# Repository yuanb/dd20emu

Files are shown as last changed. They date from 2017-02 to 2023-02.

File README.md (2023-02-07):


# dd20emu
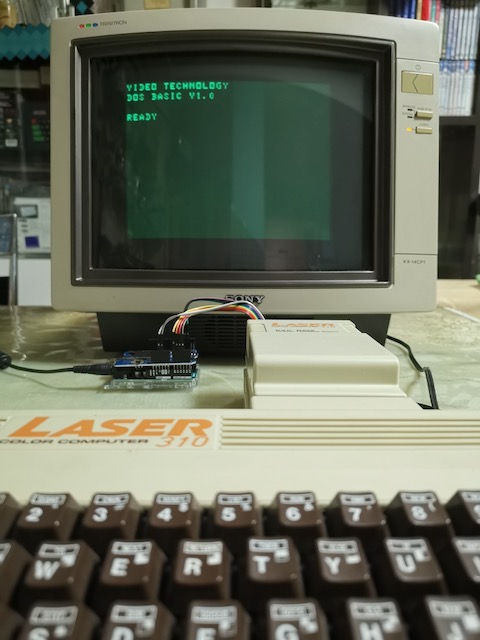
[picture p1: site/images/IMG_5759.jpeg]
dd20emu


This project is to create an Arduino UNO based Laser-200/310 DD20/DI40 Floppy drive interface and drive emulator.
At the moment this project is created, I only have a Laser-200 on hand, which has relative less amount of RAM (6K) on board. The design will include 16K (6264 SRAM x 2) memory expansion as well.

Devices I have:
* Laser 200, Basic version 1.1, 6KB RAM.
* Laser 310, Basic 2.0, 16K RAM.
* 16K RAM extension cartridge for Laser 200.
* 64K RAM extension cartridge for Laser 310.
* DD20 Floppy Drive

Todo list:
* Collect documents regarding DD20 interface and Disk image format.
* Design a 16K SRAM extension card to Laser 200
* I have about 2.25 hours length of Laser 310 data tape. They are Demo, Utilities, Games, Basic program I wrote etc. I would like to convert them to vz files. Giving they are 30 years old, the recorder I used back then was not a standard data recorder, there is only a little hope. [This link](http://www.pagetable.com/?p=32) describes how data tape encoding works on Apple I.

## Updates
2023-02-05
* Added serial terminal (Thanks https://github.com/dhansel/ArduinoFDC)
* Replaced LUT sector sync algorithm with a better one.
* Write protection

2022-02-14
Known issues:
* The emualtor is not stable when connected with DD20 floppy drive on the second port.
* Write is not supported yet.

2021-02/21  
Ported to Arduino Uno, latest code merged to develop branch.  
Used packed nibbles to store sec_lut value. 40x8 = 320 bytes.  
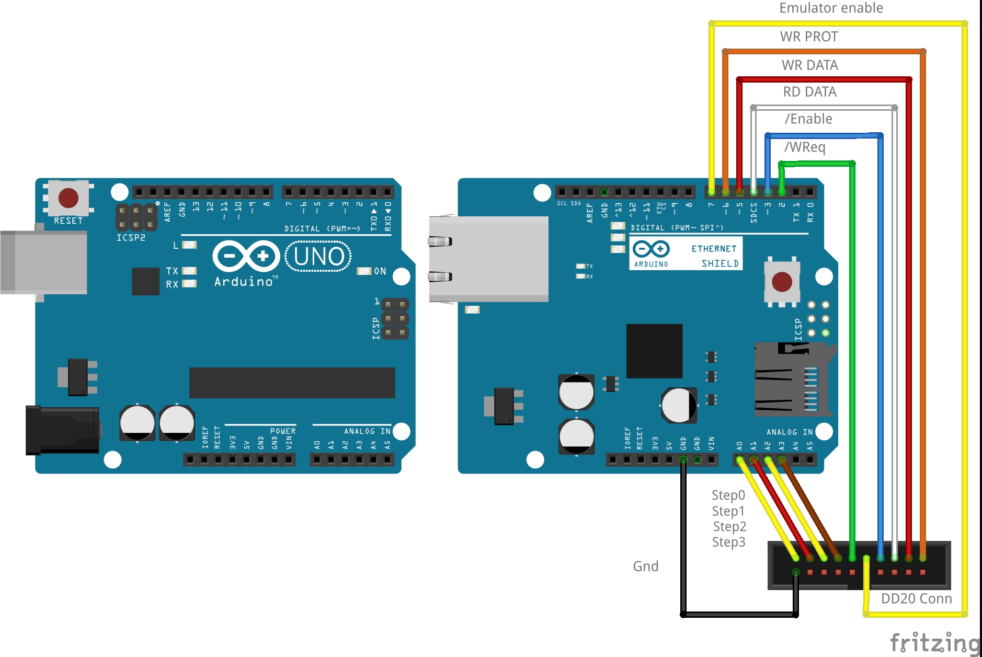
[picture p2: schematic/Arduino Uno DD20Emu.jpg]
Arduino Uno DD20 Schematic
  

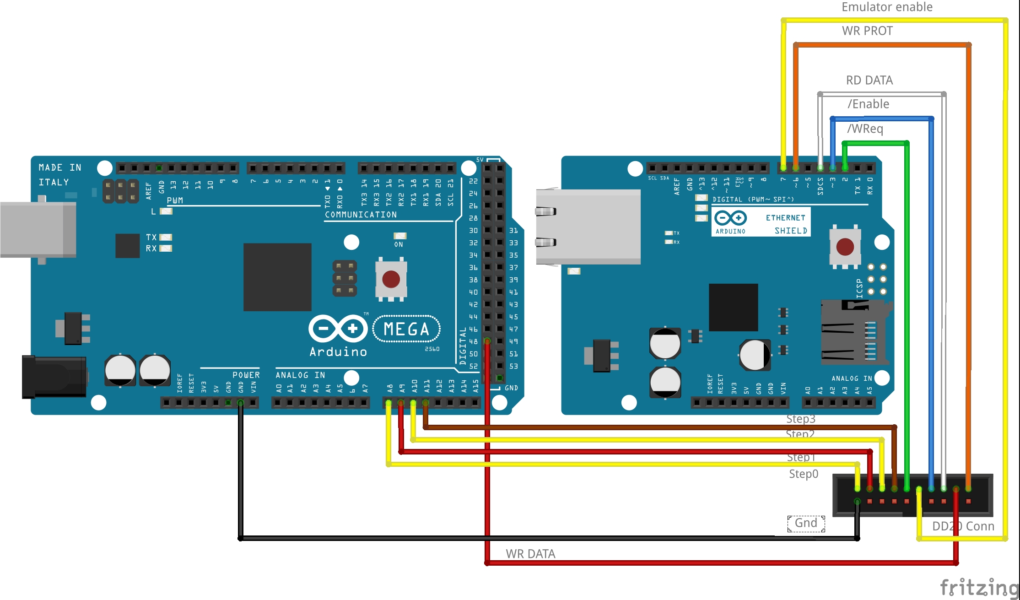
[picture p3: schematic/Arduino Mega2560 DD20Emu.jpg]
Arduino Mega2560 Schematic


2021-02/15  
Default branch: develop  
Active feature branches:  
Feature/mega2560_using_int8_sector_lut  
Feature/arduino_uno_port  

2020-11/01  
Sector lut finished. Tested with hello.dsk disk image.  

2020-10-06  
First file loadded from Arduino DD20 emu.  

2020-09-27  
First time track#0 is emulated.  
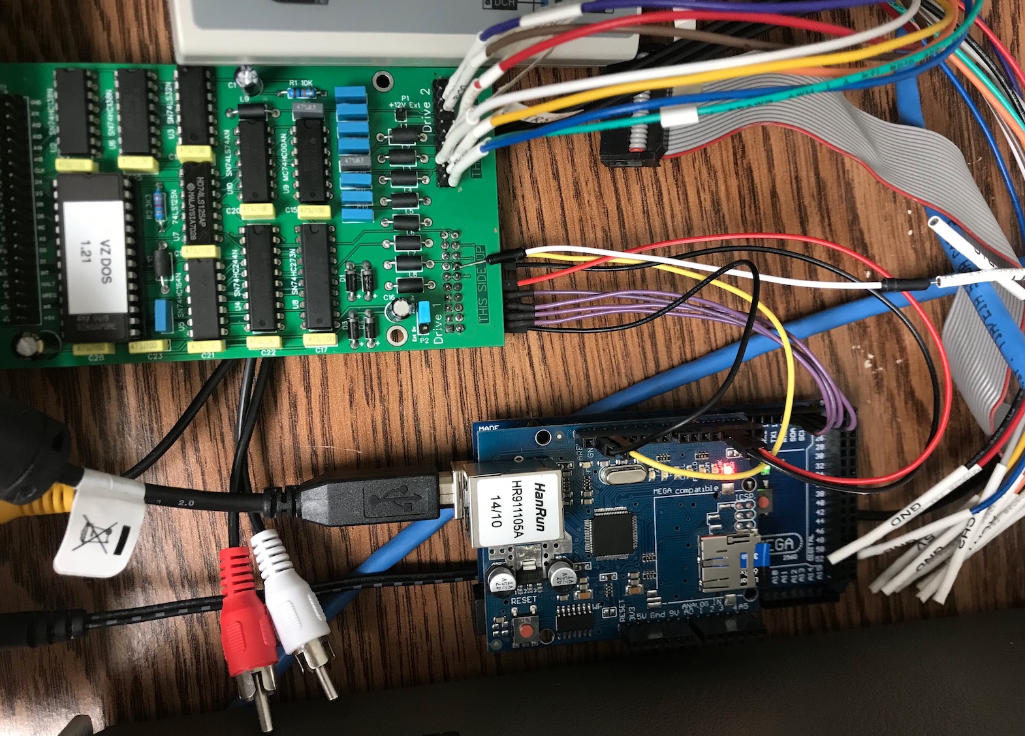
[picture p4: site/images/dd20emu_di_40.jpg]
DD20emu


2020-09-20  
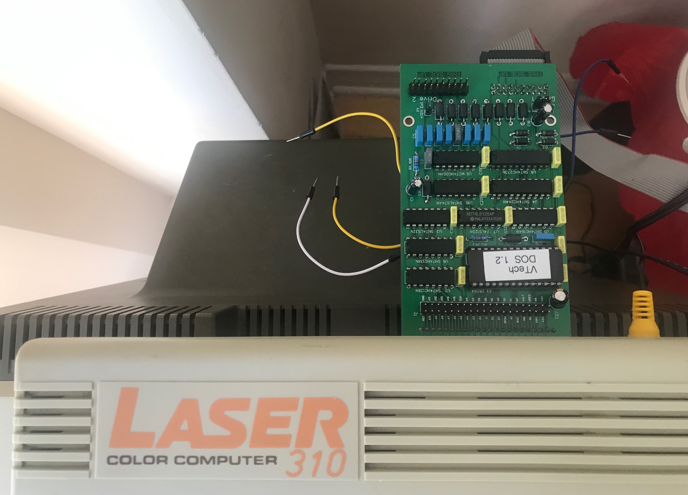
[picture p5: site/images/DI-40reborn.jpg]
DI-40 Reborn


2020-07-19  
This picture shows the RDData input is sent to 74LS164 A pin, and the D0 on port 11 read(FM Decoding). To get a byte, DI-40 needs to read from port 11 eight times.
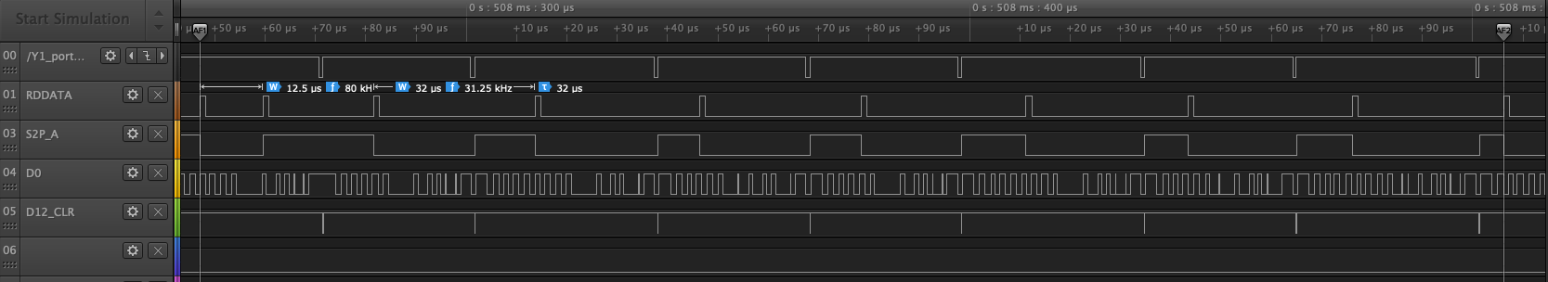
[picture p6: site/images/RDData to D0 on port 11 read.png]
FM Decoding


This picture shows the how Y1(Port11) reads generates D CLR(Port 12) pulse, 74LS164 CLK pulse and Port 12 polling.
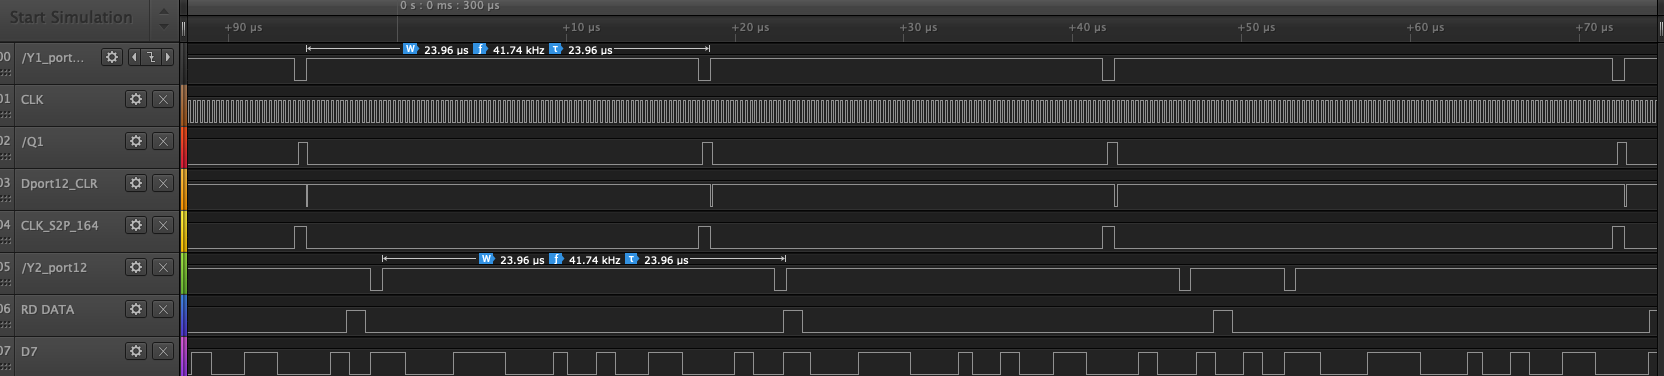
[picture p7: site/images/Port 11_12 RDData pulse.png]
D Flip-flop on port 12;74ls164 CLK and polling


2019-02-10

Started working on VZ disk reading on raspberry pi zero w.  

2019-02-02  

Finally, I got some time I can get back to this project. My plan is to use the Laser31_FPGA GPIO to connect to one or two 74AC138 decoder to trigger Arduino UNO interrupt. Arduino UNO should have enough horse power to emulate DD20 floppy drive.  
These two screen shots are the IORQ /WR and /RD requests from [Laser310_FPGA](https://github.com/zzemu-cn/LASER310_FPGA) GPIO output, decoded by 74AC138 chip(Vcc 3.3v). Y1 is the output while Laser 310 runs the following 2 lines of code.  

~~~
10 out 1,1
20 goto 10
~~~

IORQ /RD  
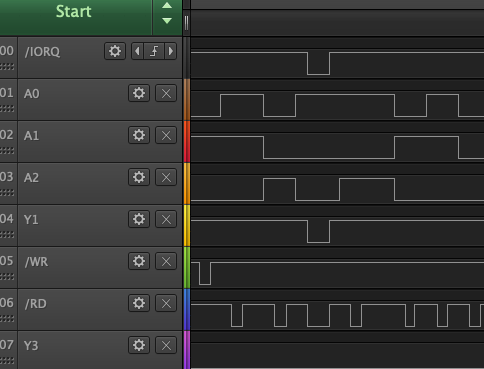
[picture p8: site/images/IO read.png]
IORQ read request on port #1

  
IQRD /WR  
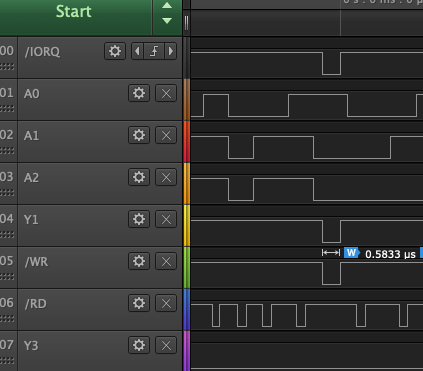
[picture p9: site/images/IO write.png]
IORQ write request on port #1


2018-09-06

Received VZ200 16K RAM Module purchased from eBay.
The 8 pin DIN socket on my Laser310 is actually RGB with composite Video output (Plus GND and PWR). There are SCART cables for SEGA Genesis 1 for that. I'm planning to purchase a SCART to RGBS (with LM1881 to split the Sync from Composite Video) from eBay.

[1200 Baud Archeology: Reconstructing Apple I BASIC from a Cassette Tape](https://www.pagetable.com/?p=32)

2017-03-29

[3ChipVZ](http://intertek00.customer.netspace.net.au/3ChipVZ/), Trying to recreate Laser200/310 with Teensy <br />

2017-03-01

With some patience, I manually decoded the Laser310 tape recording header in Audacity. Click on the images to see full pictures.Bit pulses are 1: three low/short pulses, 0: one low/short and one cycle of high/long pulses.<br />
Laser200/Laser310's cassette port operates at 600 bps Baud rate. This is a snapshot of the cassette waveforms found in VZ300 technical manual<br />
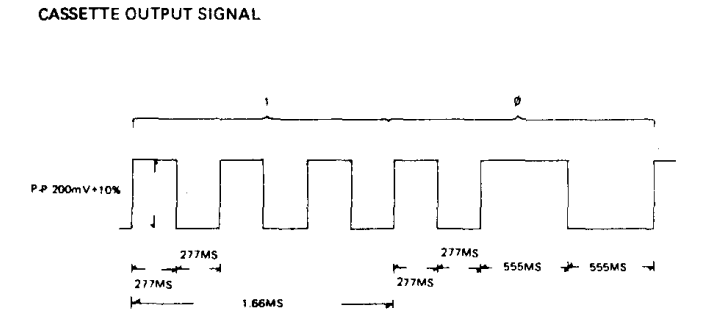
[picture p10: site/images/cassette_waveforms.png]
Laser 310 cassette waveforms

The chart above shows: 1.66ms/bit, which is 1000ms/1.66ms = 602.41bps. 0.277us/pulse, 50/50 duty cycle.<br />

It seems the Laser310 cassette program recording header is :<br />
0x80 - Leading bytes(many, about 3.61s, probably 252 bytes)<br />
0xFE - Sync bytes(5 bytes)<br />
0xF0 - File type : Basic, 0xF1 : Binary<br />
0xxx - File name (BUST OUT), up to 17 bytes<br />
0x00 - End of header, there is an extra *pause* after this byte<br /> 
0x7AE9 - Start Address, LSB first, MSB later<br />
......<br />
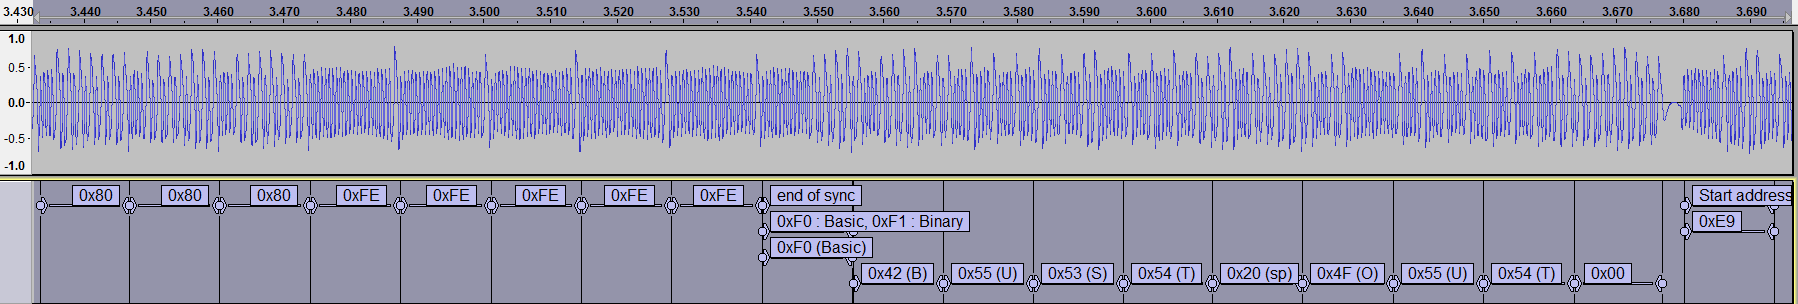
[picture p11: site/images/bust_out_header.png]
Manual decoded Laser310 game recording header


Here is a [ASCII Chart](http://www.bluesock.org/~willg/dev/ascii.html)

2017-02-20

Created dd20emu project on github.

### Some useful links
[Teensy Z80](http://labs.domipheus.com/blog/teensy-z80-part-1-intro-memory-serial-io-and-display/) Teensy serves as peripheral and ROM.<br />
[DIY EEPROM programmer](http://danceswithferrets.org/geekblog/?p=496) Arduino Mega EEPROM programmer.<br />
[Quick and Dirty Parallel FLASH programmer](https://hackaday.io/project/6275-quick-and-dirty-parallel-flash-programmer) Use an Arduino Mega and minimal parts to programme parallel FLASH.<br />

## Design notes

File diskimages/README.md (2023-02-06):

### MD5 checksums

hello.dsk : 335709d25147ab8046b958ded3ceb226

A few DD20 disk images  
Sector interlace  0, 11, 6, 1, 12, 7, 2, 13, 8, 3, 14, 9, 4, 15, 10, 5  

### Format 1  

//Disk image format 1, FLOPPY1.DSK and FLOPPY2.DSK
//Penguin wont load, D1B and VZCAVE wont run. The rest are ok
//char filename[] = "FLOPPY1.DSK";

floppy1.dsk, floppy2.dsk, 98,560 bytes  

Sector length:  

Track size: 2464 bytes  

### Format 2  
extbasic.dsk, hello.dsk, 99,184 bytes  
sector length  
0: 0x9b  
11: 0x99  
6: 0x9a  
1: 0x9a  
12:....  
5: 0x9a  

16 bytes of padding 0 between each track  
No padding at the end of last track  

Track size: 9b0/2480 bytes  

### Format 3  
empty.dsk, 99,200 bytes  

Track size: 2480  
2480x40 = 99200  

Every track is padded with 16 bytes of '0' including the last track

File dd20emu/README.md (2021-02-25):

Due to limited interrupt pins on Arduino UNO. The implementation has been changed to use PCINT interrupts.

### Arduino UNO implementation  

~~~
Pin definitions, Arduino Uno
GND
4,  PD4,    RD Data
3,  PD3,    /WRReq
2,  PD2,    /EnDrv
A3, PC3,    Step3
A2, PC2,    Step2
A1, PC1,    Step1
A0, PC0,    Step0
~~~

Step0 is on PC0[Input]  
Step1 is on PC1[Input]  
Step2 is on PC2[Input]  
Step3 is on PC3[Input]  

/En Drv is on PD2[Input]  
/WR Req is on PD3[Input]  
RD Data is on PD4[Output]  

### Arduino Mega 2560 implementation  

~~~
Pin definitions, Arduino Mega2560
GND
4 ,  PG5,    RD Data
3,   PE5,    /WrReq
2,   PE4,    /EnDrv
A11, PK3,    Step3
A10, PK2,    Step2
A9,  PK1,    Step1
A8,  PK0,    Step0  
~~~

Step0 is on PK0[Input]  
Step1 is on PK1[Input]  
Step2 is on PK2[Input]  
Step3 is on PK3[Input]  

/En Drv is on PG2[Input]  
/WR Req is on PG3[Input]  
RD Data is on PG5[Output]

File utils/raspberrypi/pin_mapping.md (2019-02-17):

FPGA:  GPIO_1,  
DE1:  JP2  

Address bus:  
GPIO_1 25 24 23 22 21 20 19 18  
A      7  6  5  4  3  2  1  0  

Data bus:  
GPIO_1 17 16 15 14 13 12 11 10  
D      7  6  5  4  3  2  1  0  

/IORQ : GPIO_1:30, JP2:35  
/WR : GPIO_1:28, JP2:33 : Raspi_pin:8,  Raspi_GPIO14  
/RD : GPIO_1:29, JP2:34 : Raspi_pin:10, Raspi_GPIO15  

GND : JP2: 12, 30  

IO PORT:  
10H : 0001 0000  
11H : 0001 0001  
12H : 0001 0010  
13H : 0001 0011  

74AC138:  
A0: : Z80_A0 : GPIO_1:18, JP2:21  
A1: : Z80_A1 : GPIO_1:19, JP2:22  
A2: : Z80_A2 : GPIO_1:20, JP2:23  
/E1 : Z80_A3 : GPIO_1:21, JP2:24  
/E2 : Z80_/IORQ  
E3: : Z80_A4 : GPIO_1:22, JP2:25  

/O0(Y0) : Raspi_pin:12, Raspi_GPIO18  
/O1(Y1) : Raspi_pin:16, Raspi_GPIO23  
/O2(Y2) : Raspi_pin:18, Raspi_GPIO24  
/O3(Y3) : Raspi_pin:22, Raspi_GPIO25

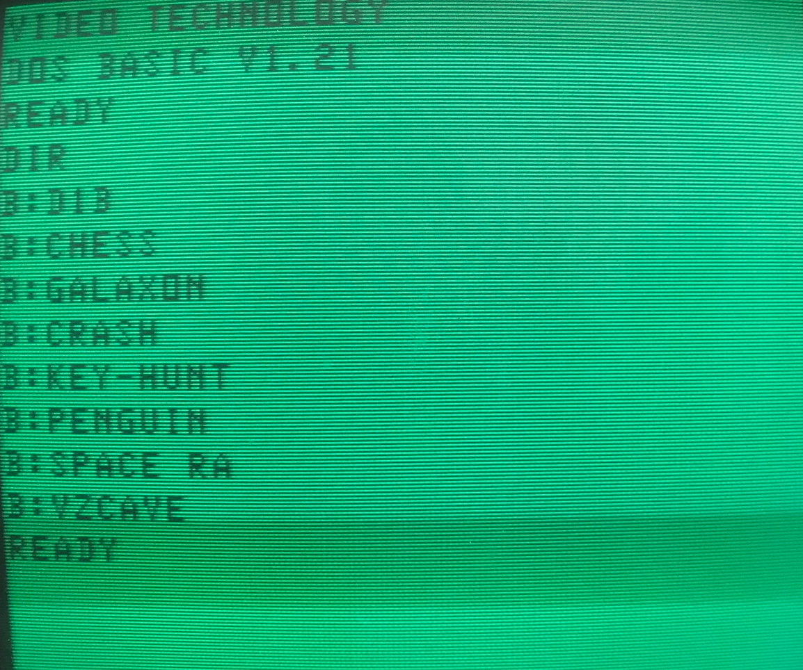
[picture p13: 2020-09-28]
site/images/dir_cmd.jpg

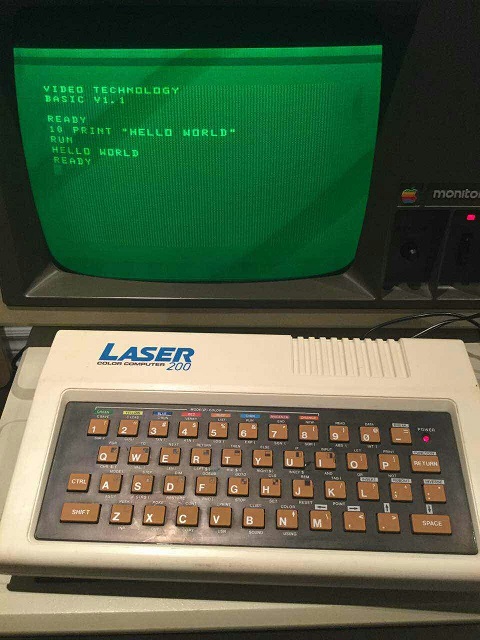
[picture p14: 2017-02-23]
site/images/Laser200.jpg

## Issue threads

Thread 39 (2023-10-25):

Laser DOS v1.1

bushy555, 2023-10-25:
Hi Yuan,
Just reading through your very interesting project.
I noticed that you have BASIC ROM version 1.1
This is the only ROM version that we do not have in the entire VZ/Laser software collection.
Is there any chance of downloading this into a binary format and sharing ?

A few of us enthusiasts on the VZ/Laser facebook page would love to have this BASIC ROM version added to our collection.
Thanks
-dave.

bushy555, 2023-11-20:
Thankyou - that would be wonderful.! If I can help you in anyway, please sing out.

I was the *stupid* person whom hand-typed out v1.2 rom way back in late '98 for the first emulator 'vzem' written by Guy Thomason. Took me six weeks with good old Windows DEBUG and tens & tens of VZ printouts of the ROM in hex.
Cheers

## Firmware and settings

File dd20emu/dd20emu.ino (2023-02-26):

/*
    DD-20 emulator
    Copyright (C) 2020-2023 https://github.com/yuanb/dd20emu

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
    You should have received a copy of the GNU General Public License
    along with this program.  If not, see <https://www.gnu.org/licenses/>.
*/

/* Libraries used:
 *  SDFat : Author : Bill Greiman, Tested: 2.2.0, https://github.com/greiman/SdFat
 *  PinChangeInterrupt : Tested 1.2.9, https://github.com/NicoHood/PinChangeInterrupt
 *
 *  Libraries can be installed from Arduino IDE menu Tools\Manage Libraries
 */

/*
 * TODO:        
 * 1. Write support
 * 2. Save configurations to EEPROM
 */
#define __ASSERT_USE_STDERR
#include <assert.h>

#include <SPI.h>
#include "SdFat.h"
#include "PinChangeInterrupt.h"
#include "dd20emu_acl.h"
#include "vzdisk.h"

/*
 * Laser 310 I/O port
   Port 10h     Latch(write-only)
        11h     DATA(read-only)
        12h     Pooling(read-only)
        13h     Write protection status(read-only)
*/

#define FILENAME_MAX  80
char diskimage[FILENAME_MAX] = "HELLO.DSK";
vzdisk *vzdsk = NULL;

bool write_protect = false;

void setup() {
  Serial.begin(9600);
  while (!Serial) {
    ; // wait for serial port to connect. Needed for native USB port only
  }

  // put your setup code here, to run once:
  // set the digital pin as output:
  pinMode(LED_BUILTIN, OUTPUT);
  pinMode(wrLedPin, OUTPUT);
  digitalWrite(wrLedPin, LOW);
  
  //DEBUG: debug code for logic analyzer
  pinMode(icpFollowerPin, OUTPUT);
  digitalWrite(icpFollowerPin, HIGH);
  pinMode(icpEnabledPin, OUTPUT);
  digitalWrite(icpEnabledPin, HIGH);
  //DEBUG: debug code for logic analyzer
  

  pinMode(emuEnPin, INPUT);

  pinMode(wrProtPin, OUTPUT);
  digitalWrite(wrProtPin, write_protect);

  pinMode(enDrvPin, INPUT_PULLUP);
  pinMode(rdDataPin, OUTPUT);
  pinMode(wrReqPin, INPUT_PULLUP);
  pinMode(wrDataPin,INPUT_PULLUP);

  pinMode(stepPin0, INPUT_PULLUP);
  pinMode(stepPin1, INPUT_PULLUP);
  pinMode(stepPin2, INPUT_PULLUP);
  pinMode(stepPin3, INPUT_PULLUP);

  vzdsk = new vzdisk();
  vzdsk->Open(diskimage); 

  attachInterrupt(digitalPinToInterrupt(wrReqPin), writeRequest, CHANGE);
  attachInterrupt(digitalPinToInterrupt(enDrvPin), driveEnabled, CHANGE);
  attachPinChangeInterrupt(digitalPinToPinChangeInterrupt(stepPin0), handle_steps, CHANGE);
  attachPinChangeInterrupt(digitalPinToPinChangeInterrupt(stepPin1), handle_steps, CHANGE);
  attachPinChangeInterrupt(digitalPinToPinChangeInterrupt(stepPin2), handle_steps, CHANGE);
  attachPinChangeInterrupt(digitalPinToPinChangeInterrupt(stepPin3), handle_steps, CHANGE); 

  print_status();
  print_enter_shell_msg();
  initICPTimer();
}

void loop() {
  handle_datastream();
  handle_shell();
}

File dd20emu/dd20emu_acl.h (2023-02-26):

/*
    DD-20 emulator
    Copyright (C) 2020-2023 https://github.com/yuanb/dd20emu

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
    You should have received a copy of the GNU General Public License
    along with this program.  If not, see <https://www.gnu.org/licenses/>.
*/

#ifndef _DD20EMU_ACL_H_
#define _DD20EMU_ACL_H_

#ifdef ARDUINO_AVR_UNO
/*
 * 
 * Arduino Uno pinout 
 * https://upload.wikimedia.org/wikipedia/commons/c/c9/Pinout_of_ARDUINO_Board_and_ATMega328PU.svg
 * 
 * Ethernet shield datasheet
 * https://www.mouser.com/catalog/specsheets/a000056_datasheet.pdf
 * Ethernet shield schametic , 
 * Arduino Uno Pin 4 is used as SD-CS, can not be used as GPIO
 * Arduino Uno Pin 10 is used as W5100 CS, can not be used as GPIO
 * 11,12,13 on ICSP header are for SPI
 * https://www.arduino.cc/en/uploads/Main/arduino-ethernet-shield-05-schematic.pdf
*/

// SD chip select pin.  Be sure to disable any other SPI devices such as Enet.
#define SD_CS_PIN 4

/*
 * Pin definitions, Arduino Uno
 * GND
 * 7,  PD7,    Emulator enable
 * 6,  PD6,    WR PROT
 * 5,  PD5,    WR Data
 * 4,  PD4,    RD Data
 * 3,  PD3,    /WRReq
 * 2,  PD2,    /EnDrv
 * A3, PC3,    Step3
 * A2, PC2,    Step2
 * A1, PC1,    Step1
 * A0, PC0,    Step0
*/

/* Port and bit for Emu EN */
#define PORT_EMUEN    PIND
#define PIN_EMUEN_BIT 7
const byte emuEnPin = 7;

/* Port and bit for Write LED */
#define PORT_WRLED    PORTB
#define WRLED_DATA_BIT  0
const byte wrLedPin = 8;

/* Port and bit for WR PROT */
#define PORT_WRPROT   PORTD   //used in dd20emu.ino
#define WP_DATA_BIT 6
const byte wrProtPin = 6;

/* Port and bit for RDDATA */
#define PORT_RDDATA   PORTD   //rddata.ino
#define RD_DATA_BIT 4
const byte rdDataPin = 4;

/* Port and bit for WRDATA */
#define PORT_WRDATA   XXX   //used in rddata.ino
#define WR_DATA_BIT XXX
const byte wrDataPin = XXX

/* Port and bits for /EnDrv and /WRReq */
#define PORT_CTL      PIND    //isr.ino
#define PIN_EN_BIT      3
#define PIN_WRREQ_BIT   2
const byte enDrvPin  = 3;
const byte wrReqPin  = 2;

/* Port and bits for Step 0 ~ Step 3 */
#define PORT_STEP     PINC    //isr_steps.ino
#define PIN_STEP3_BIT   3
#define PIN_STEP2_BIT   2
#define PIN_STEP1_BIT   1
#define PIN_STEP0_BIT   0
const byte stepPin3  = A3;
const byte stepPin2  = A2;
const byte stepPin1  = A1;
const byte stepPin0  = A0;

#elif ARDUINO_AVR_MEGA2560

// SD chip select pin.  Be sure to disable any other SPI devices such as Enet.
#define SD_CS_PIN SS

/*
   Pin definitions, Arduino Mega2560
   GND
   7,   PH4,    Emulator enable
   6,   PH3,    WR PROT
   5,   PE3,    WR Data
   4 ,  PG5,    RD Data
   3,   PE5,    /EnDrv
   2,   PE4,    /WRReq
   18,  PD3,    Step3
   19,  PD2,    Step2
   20,  PD1,    Step1
   21,  PD0,    Step0  
*/

/* Port and bit for Emu EN */
#define PORT_EMUEN    PINH
#define PIN_EMUEN_BIT 4
const byte emuEnPin = 7;

/* Port and bit for Write LED */
#define PORT_WRLED    PORTH
#define WRLED_DATA_BIT  5
const byte wrLedPin = 8;

//DEBUG: debug code for logic analyzer
#define PORT_ICPFOLLOWER  PORTH
#define FOLLOWER_BIT 6
const byte icpFollowerPin = 9;
#define PORT_ICPENBL      PORTB
#define _ICPENBL_BIT  4
const byte icpEnabledPin = 10;
//DEBUG: debug code for logic analyzer


/* Port and bit for WR PROT */
#define PORT_WRPROT   PORTH   //used in dd20emu.ino
#define WP_DATA_BIT 3
const byte wrProtPin = 6;

/* Port and bit for RDDATA */
#define PORT_RDDATA   PORTG   //rddata.ino
#define RD_DATA_BIT 5
const byte rdDataPin = 4;

/* Port and bit for WRDATA ICP5*/
#define PORT_WRDATA PINL   //PL1 used in wrdata.ino
#define WR_DATA_BIT 1
const byte wrDataPin = 48;

/* Port and bits for /EnDrv and /WRReq */
#define PORT_CTL      PINE    //isr.ino
#define PIN_EN_BIT      5
#define PIN_WRREQ_BIT   4
const byte enDrvPin  = 3;
const byte wrReqPin  = 2;

/* Port and bits for Step 0 ~ Step 3 */
#define PORT_STEP     PINK    //isr_steps.ino
#define PIN_STEP3_BIT   3
#define PIN_STEP2_BIT   2
#define PIN_STEP1_BIT   1
#define PIN_STEP0_BIT   0
const byte stepPin3  = A11;
const byte stepPin2  = A10;
const byte stepPin1  = A9;
const byte stepPin0  = A8;
#endif

#else
/* TODO, add support Arduino Nano every */
#error "Unsupported architecture"

#endif  //_DD20EMU_ACL_H_

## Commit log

2017-03-01 Add decoded Laser310 tape header image
2021-02-22 Develop to master (Arduino UNO/Mega2560), (#16)
    * added direct gpio tests
    * added port 11H and 12H implementation
    * Update dd20emu.ino
    * Update dd20emu.ino
    * separated files
    * First successful track#0 rddata attempt
    * put_track() -> put_sector()
    * Update dd20emu.ino
    * Optimized handle_steps()
    1. Optimized handle_steps()
    2. Minor optimization on file handling
    * Single sector access
    Switched to single sector access.
    Minor optimizations on ISR code.
    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
    [dd20emu.ino, dd20emu_acl.h, directgpio.c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]
2021-02-23 Added license headers (#18)
    * single sector access cleanup
    * First time a program is loaded
    I can load large program with no problem.
    At about the same speed of a real DD20.
    Isr_steps.ino didn't work.
    * Code cleanup
    * Cleanup, comments on dsk fo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
    [dd20emu.ino, dd20emu_acl.h, isr.ino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]
2021-02-25 Added license header (#20)
    * Cleanup, comments on dsk for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
    [Arduino UNO DD20Emu.fzz]
2021-03-12 Develop to Master (#25)
    * Cleanup, comments on dsk format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
    [Arduino Mega2560 DD20Emu.fzz, Arduino UNO DD20Emu.fzz]
2021-07-29 Develop to Master (#26)
    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
2023-01-21 Removed duplicated files
    [Arduino UNO DD20Emu.fzz]
2023-01-29 Wrdata (#30)
    * Added WRDATA pin support, misc code clean up
    * Updated schematics
    * added logic2 capture on wrdata
    [Arduino Mega2560 DD20Emu.fzz, Arduino UNO DD20Emu.fzz]
2023-02-03 initial Shell (#31)
    * added shell
    * added dumpsector
    * Shell cmd::dir, mount
    Implemented shell command : dir and mount
    Updated file headers
    * tempbuffer -> dynamic
    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
2023-02-06 Time1 datastream (#32)
    * Create time1_datastream.ino
    * Update rddata.ino
    * better WR request detection
    * updated images
    * added trklist, code cleanup
    * separated track offset calculation into get_track_offset()
    * get_sector1 is almost done
    Locks on GAMES.DSK and GAMES2.DSK. Both are corrupted.
    Other disk images are ok
    * added a comment
    * get_sector1() ok
    * renamed blank disk image
    * Updated comments
    * done with sector finding algorithm, for now
    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
    [dd20emu.ino, isr_steps.ino, rddata.ino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]
2023-02-07 Wr support code cleanup (#33)
    * Added Write protection support
    * Update README.md
    [Arduino Mega2560 DD20Emu.fzz, Arduino UNO DD20Emu.fzz]
2023-02-07 Added emulator enable detection (#36)
    [Arduino Mega2560 DD20Emu.fzz, Arduino UNO DD20Emu.fzz]
2023-02-14 Wr support1 (#37)
    * Update utilities.ino
    * Update save_hello2_rddata_wrdata_realdd20.sal
    * Create Write flux.png
    * Renamed file
    * Update save_hello2_rddata_wrdata_realdd20.sal
    * Update utilities.ino
    * Revert "Update utilities.ino"
    This reverts commit f4d7f90394e354f3ec710aab0491af5afa98f0c9.
    * wr led and emuen
    * finished catalog()
    * code clean up
    * Fixed backspace on Mac (0x7f)
    * code optimization for sub bit wr request checking
    * added write protection support
    [dd20emu.ino, dd20emu_acl.h, isr.ino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]
2023-02-26 Wr support2 (#38)
    * Moved WR DATA to ICP5
    * Update dd20emu_acl.h
    * added debugging pins: intEnbl and icp follower
    Buffer overflow issue!
    * cleanup
    * code cleanup with stdint types
    * Update vzdisk.h
    * first success on receiving bit stream
    * change to volatile variables for isr functions
    * code cleanup
    * added timer counter dump
    * Update shell.ino
    [Arduino Mega2560 DD20Emu.fzz]

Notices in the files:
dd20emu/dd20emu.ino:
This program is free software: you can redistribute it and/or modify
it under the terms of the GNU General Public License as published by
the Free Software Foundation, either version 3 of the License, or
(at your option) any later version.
